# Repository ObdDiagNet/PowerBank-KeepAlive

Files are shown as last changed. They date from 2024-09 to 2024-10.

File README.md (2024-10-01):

Power Bank Keep Alive
==========================================
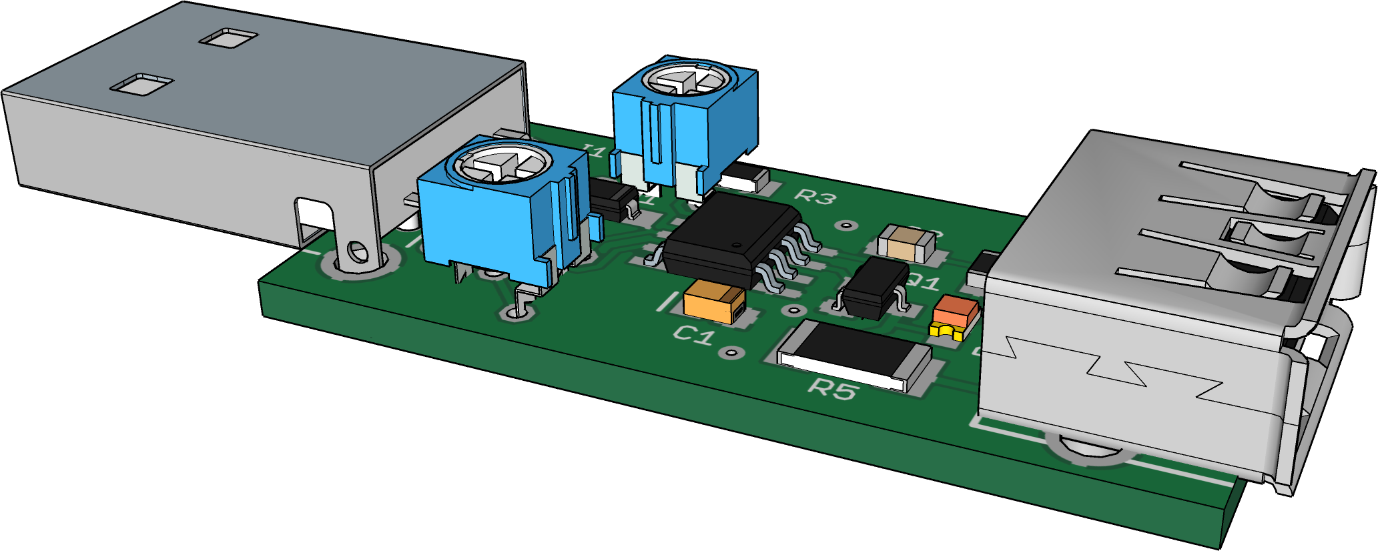
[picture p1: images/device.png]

<p>Power banks often shut down when connected to low current devices as they designed to provide a power while charging a smartphone and to cut it off when the current drops below the threshold. This project started when I wanted to power my smartphone acting as a tethering device when camping. Eventually, smartphone battery died but charging from power bank didn’t kick off. The smartphone and power bank were placed on top of nearest pine tree to provide a better reception and it was a challenge every time remove it and charge. The next time my friend got a smartphone with weak battery and powering it from power bank didn’t help either as it disconnected the exact moment when smartphone charging completed and not resumed charging when smartphone battery was low. I have figured out that simulating a load through periodic current draw, around 100 mA, shorter than the power bank’s shutdown interval, could prevent the power bank from powering turning off. The idea is not new, I have seen similar schematic posted on the Web in many places. The device is built around CMOS 555 timer to minimize the current draw by timer itself. The gate resistor for Q1 is not required as CMOS timer has a sufficient source resistance themselves. The frequency and duty cycle adjusted using trim potentiometers to set to minimum power consumption but keep the power bank alive. The LED allows you to see the device activity. Some power banks require about 100 mA load current to keep them alive but it could be less, 50 or even 15 mA. Actually, if your power bank needs only 15 mA you do not need this device, just connect 330 ohm resistor to make it happy. On contrary, some power banks seem to be checking for constant power consumption and simulating periodical loads not helping to trick them. My original idea was to keep the duty cycle fixed and adjust only frequency but unfortunately it didn’t work and schematic ended up with two trimmers.</p><p><b>Note: Printed circuit board layout is in Eagle 9 format.</b><p>
<p>&nbsp;</p>
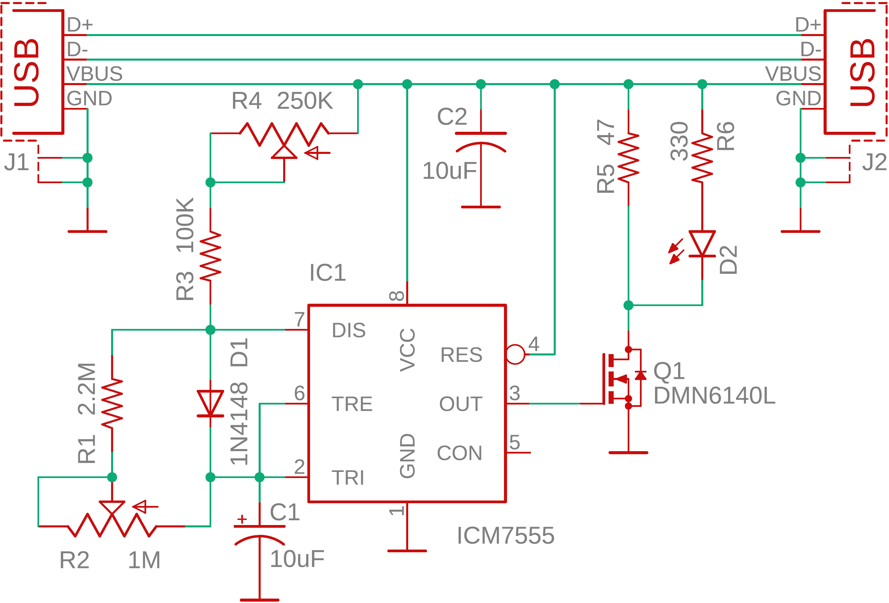
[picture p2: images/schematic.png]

<p>These blank PCBs are available from PCBWay: http://www.pcbway.com/project/shareproject/Keep_power_bank_alive_26bb6bb9.html</p>

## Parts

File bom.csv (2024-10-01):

Parts | Value | Package | Description | Note
J1 |  | USB-A-H | USB type a plug right angle t/h
J2 |  | USB-A-FEMALE | USB type A receptacle right angle t/h
C1 | 10uF 10V | 0805 | Tantalum SMD capacitor
C2 | 10uF 10V | 0805 | Ceramic SMD capacitor
R1 | 2.2M | 0805 | SMD resistor
R2 | 1M | 3306P | Bourns 3306P-1-254
R3 | 100K | 0805 | SMD resistor
R4 | 250K | B25P | Bourns 3306P-1-254
R5 | 47 | R2010 | SMD resistor
R6 | 330 | 0805 | SMD resistor
D1 | 1N4148 | SOD123 | SMD diode
D2 | Red | 0805 | SMD LED
Q1 | DMN6140L | SOT23 | DMN6140L-13 | Could be TLC555 or other CMOS 555 timers
IC1 | ICM7555 | SO-8 | CMOS 555 timer | Could be PMV450ENEA, NDS7002A

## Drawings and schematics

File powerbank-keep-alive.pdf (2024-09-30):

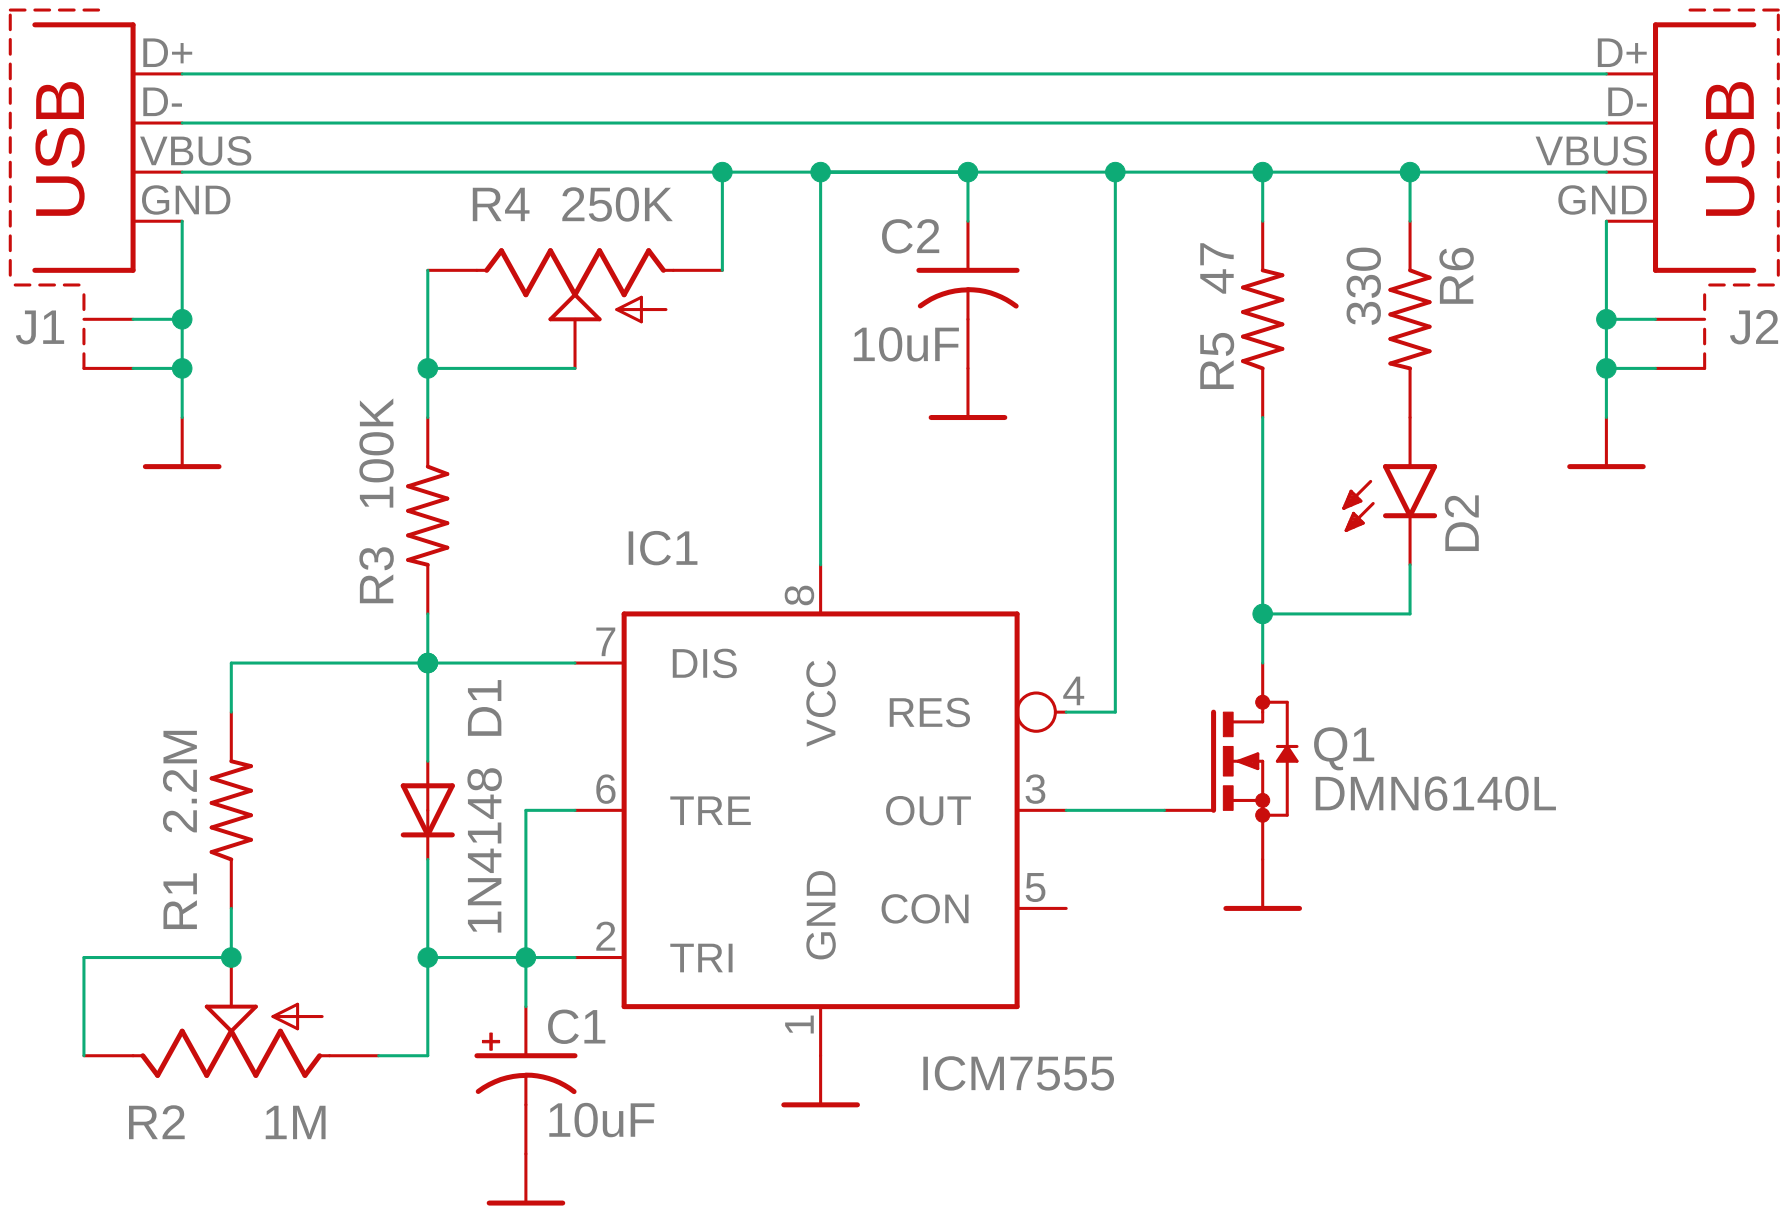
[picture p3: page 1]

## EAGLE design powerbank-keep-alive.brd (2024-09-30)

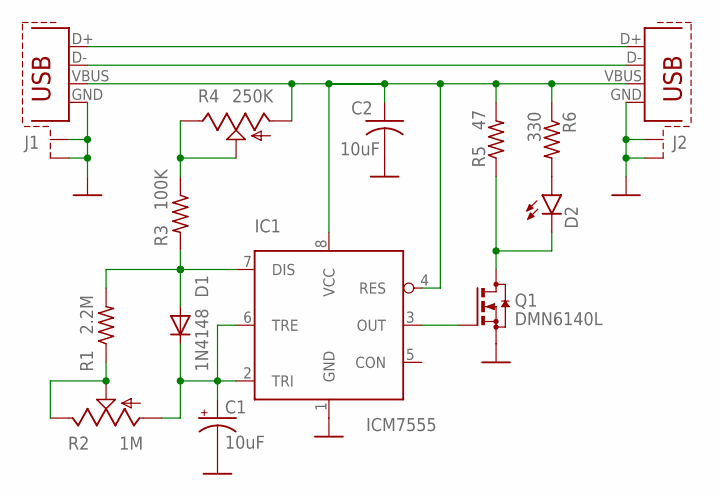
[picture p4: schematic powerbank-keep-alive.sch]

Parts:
C1: 10uF; CPOL_0805
C2: 10uF; C0805
D1: 1N4148; SOD123
D2: Red; CHIP-LED0805
IC1: ICM7555; SO-8
J1: USB-SHIELD-A-H; USB-A-H
J2: USB-SHIELD-FEMALE; USB-A-FEMALE
Q1: DMN6140L; SOT23
R1: 2.2M; R0805
R2: 1M; B25P
R3: 100K; R0805
R4: 250K; B25P
R5: 47; R2010
R6: 330; R0805

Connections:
GND: C1.-, C2.2, IC1.1 (GND), J1.GND, J1.GND2 (S1), J1.GND3 (S2), J2.GND, J2.S1, J2.S2, Q1.2 (S)
unnamed: C1.+, D1.C, IC1.2 (TRI), IC1.6 (TRE), R2.A
unnamed: IC1.3 (OUT), Q1.1 (G)
unnamed: D2.C, Q1.3 (D), R5.1
unnamed: D2.A, R6.2
unnamed: D1.A, IC1.7 (DIS), R1.2, R3.2
unnamed: R3.1, R4.E, R4.S
unnamed: R1.1, R2.E, R2.S
unnamed: J1.D-, J2.D-
unnamed: J1.D+, J2.D+
PWR: C2.1, IC1.4 (RES), IC1.8 (VCC), J1.VBUS, J2.VBUS, R4.A, R5.2, R6.1

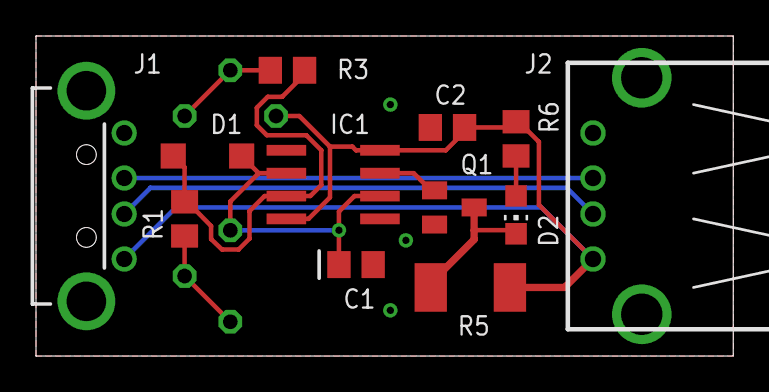
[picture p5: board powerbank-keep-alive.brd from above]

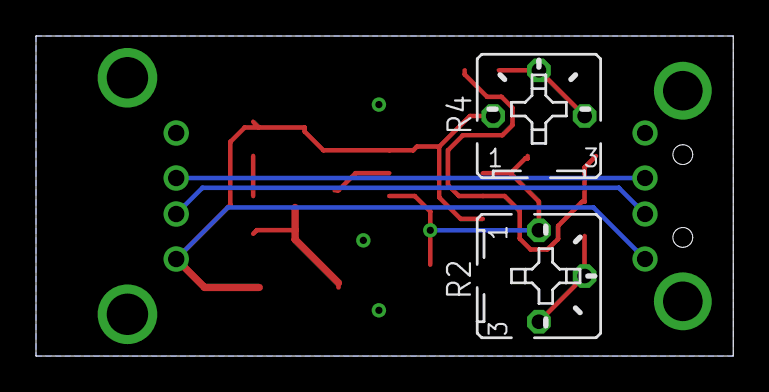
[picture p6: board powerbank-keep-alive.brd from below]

Board: 2 copper layers, 38.7 x 17.8 mm, 14 parts (2 on the bottom side), 11 nets.

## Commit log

2024-09-30 Added project files
    [powerbank-keep-alive.brd, powerbank-keep-alive.sch]
2024-09-30 Tantalum capacitor value
    [powerbank-keep-alive.brd, powerbank-keep-alive.sch]
2024-10-01 Added BOM
    [bom.csv]
